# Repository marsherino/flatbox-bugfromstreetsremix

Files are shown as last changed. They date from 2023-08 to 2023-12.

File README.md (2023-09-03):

# Flatbox, Bug from Streets™ Remix: a low profile, low cost leverless arcade controller with right thumb action button and simplified fourth column.

This repository contains 3D-printable models and the PCB design files needed to make an arcade controller that looks like this:

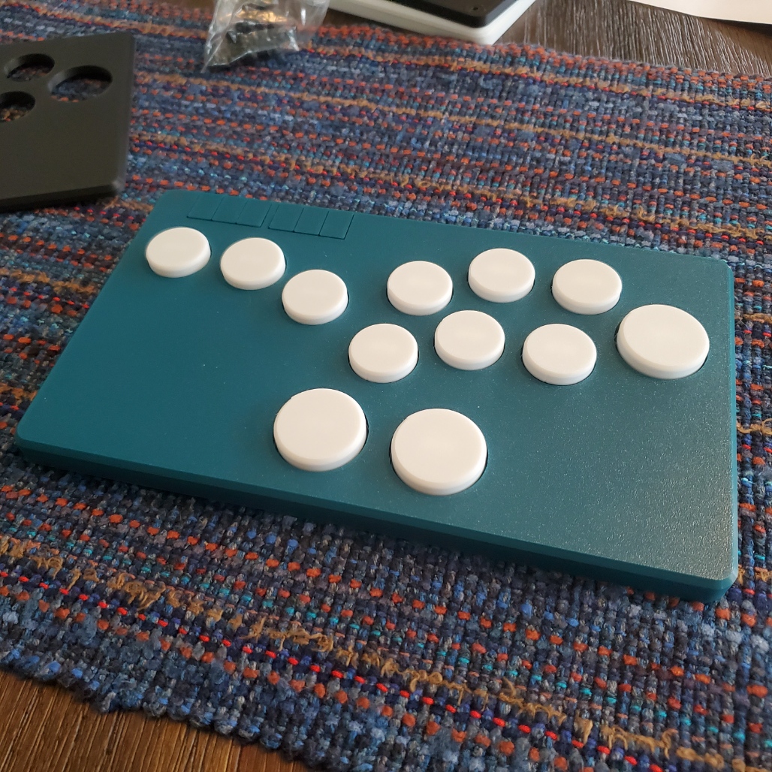
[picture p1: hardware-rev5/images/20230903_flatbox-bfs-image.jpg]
Flatbox BFS Remix


There are two versions of this controller on this Flatbox fork: one based on the architecture of the Flatbox rev4 (embedded RP2040 chip), and the other based on the Flatbox rev5 (Waveshare RP2040-Zero), both originally by jfedor2. The rev5 version of this remix is complete and available; the rev4 version is still in development.

Please see the READMEs for each version for instructions on component purchasing and assembly.

Both controllers run on [GP2040-CE firmware](https://gp2040-ce.info/) developed by the Open Stick Community and use Kailh low profile Choc v1 keyboard switches for both movement and action buttons.

Both controllers have five input modes: XInput, Nintendo Switch, PS3, PS4, and keyboard.

The table below lists each version's specifications.

version | [rev4] | [rev5]
------- | --------------------- | ---------------------
case dimensions | 218x130x10mm | 218x126x10mm
chipset | embedded RP2040 | [RP2040-Zero](https://www.waveshare.com/rp2040-zero.htm)
port | USB-C | USB-C
SMT assembly required | yes | no

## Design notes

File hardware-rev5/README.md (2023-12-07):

# Flatbox rev5

This is rev5 of the Flatbox. In this version an [RP2040-Zero](https://www.waveshare.com/rp2040-zero.htm) board is soldered onto the main PCB. This eliminates the need for SMT / SMD Assembly, which reduces the per-board cost from your PCB supplier (I use JLCPCB) in exchange for requiring slightly more soldering work from you. This makes it ideal for hobbyists and small board runs in general.

To make one unit you will need:

* [3D printed case parts](3d-printed-case), a top and a bottom;
* [The Flatbox PCB](pcb), ordered per the instructions below;
* [A RP2040-Zero](https://www.waveshare.com/rp2040-zero.htm), making sure you get the option **without header**;
* Twelve (12) [Kailh Choc v1 Low Profile switches](https://chosfox.com/collections/kailh-low-profile-switch-pg1350/products/kailh-low-profile-choc-switches) of your choice;
* Twelve (12) [Kailh Choc PG1350 hotswap sockets](https://chosfox.com/products/kailh-choc-switch-1350-hot-swap-sockets?_pos=1&_sid=1d99bca9e&_ss=r), optional but highly recommended;
* A set of [3D printed buttoncaps](../3d-printed-buttoncaps), nine (9) at 24mm size and three (3) at 30mm size;
* Six (6) [6x6x5mm tact switches](https://www.amazon.com/dp/B07VSNN9S2), noting that you'll need tact switches with longer stems if you use another case design that uses either the plain stems or stem caps instead of integrated button tabs;
* Seven (7) [M3x6mm flat head screws](https://www.amazon.com/dp/B01E5EOIWW);
* Some kind of rubber feet (6mm / 0.25 in preferred) or non-slip padding for the bottom;
* A strong adhesive to attach the feet (I use epoxy);
* Non-marking tape, like blue painter's tape; and
* Soldering equipment.

## Ordering the Boards

I order my boards from [JLCPCB](https://jlcpcb.com/).

1. Make an account and sign in.

2. Click "order now" at the top right of the screen.

3. You will see the following page:

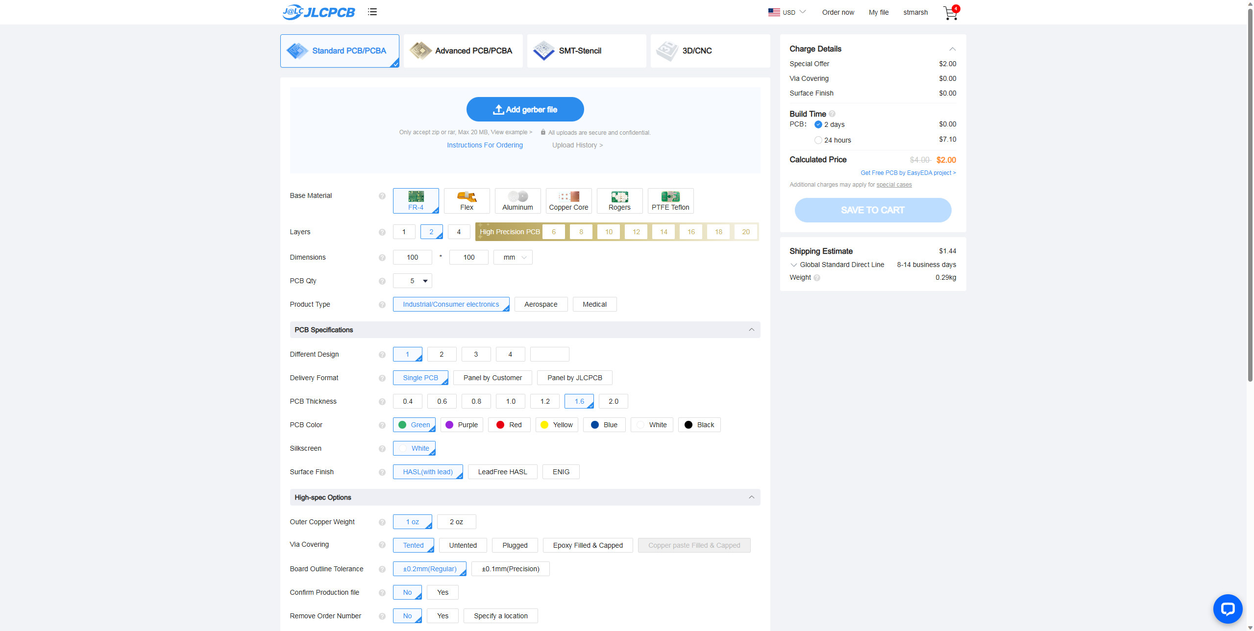
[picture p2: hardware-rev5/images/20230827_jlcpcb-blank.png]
JLCPCB blank page


Download the Gerber files included in this repository, click the blue button that reads "Add Gerber file," and upload the Gerber file. It will need to be a .zip or .rar file for JLC to accept it.

4. You will then see the following page:

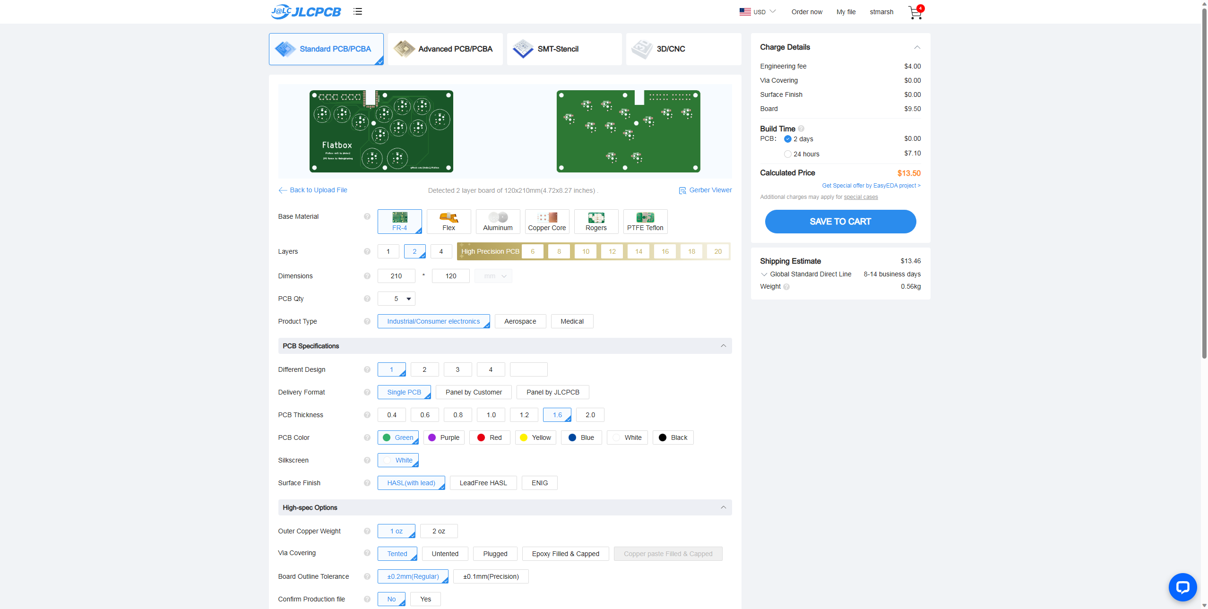
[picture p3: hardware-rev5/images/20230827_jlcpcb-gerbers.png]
JLCPCB with Gerbers added


You can leave most of these settings at default, but for the sake of completeness, here are the settings I use:

* **Base Material**: FR-4 (default)  
* **Layers**: 2  
* **Dimensions**: auto-populated, do not adjust  
* **PCB Quantity**: As many as you want, minimum of 5. Avoid ordering more than 50 boards in one order, because if you order more than 50, you won't be able to use Single PCB delivery format, which will require extra processing from you.  
* **Product Type**: Industrial / Consumer Electronics  
* **Different Design**: 1  
* **Delivery Format**: Single PCB  
* **PCB Thickness**: 1.6  
* **PCB Color**: Up to you. Green boards will generally ship a day or two faster than other colors.  
* **Silkscreen**: This will auto-populate depending on your color choice. Every color except for White will have a white silkscreen; the White color will have a black silkscreen.  
* **Surface Finish**: HASL (with lead) or LeadFree HASL  
* **Outer Copper Weight**: 1 oz  
* **Via Covering**: Tented  
* **Board Outline Tolerance**: ±0.2mm (regular)  
* **Confirm Production File**: Up to you. I recommend Yes here, because it will allow you to double-check the board to make sure everything's right before JLCPCB makes it for a minimal cost.  
* **Remove Order Number**: Up to you; this is a cosmetic choice. JLCPCB will print the order number on your boards somewhere if you pick No. If you pick Yes, they won't, but the order will be slightly more expensive. I usually pick Yes.  
* **Flying Probe Test**: Fully test  
* **Gold Fingers**: No  
* **Castellated Holes**: No  
* **PCB Assembly**: No  
* **Stencil**: No  

For reference, as of this writing (August 2023), 5 boards with the above settings costs about $16 USD before shipping. 50 boards will cost about $70 USD before shipping.

5. Click "Save to Cart," check out, and complete your order.

## Assembling the PCB

1. Once you've received all your parts, set out your soldering workspace:

Soldering layout

When soldering, make sure your workspace is clean and that you have adequate ventilation - this can be as simple as opening a window and running a fan away from your workspace. For this project, it's easy to do all of the work on a flat surface, so I just use non-marking, low-adhesion tape like blue painter's tape to hold down the PCB while I'm working on it. When working with solder, **make absolutely sure** that you wash your hands before and after soldering; do not eat or place your hands near your eyes or mouth while working; and make sure you ground yourself (either by using an anti-static wristband or by touching a grounded metal object, like the screw in a lightswitch plate) before you handle electronics.

2. Tape down your board and preheat your soldering iron per the standards for your solder. For standard leaded, rosin-core solder (what I use and recommend), I tend to work at 350 to 360°C, but you can go higher depending on your preferences.

Taped board

3. Align the RP2040-Zero. You want to make sure that all of the castellated pins on the board (the silver areas with the small holes) align with the pads on the PCB.

aligned board

4. Tape down the RP2040-Zero. You only need to leave a couple of pins at the bottom exposed for now - once those are soldered, the board will hold in place and you can remove the tape.

taped rp2040

If you prefer, it's also possible to apply some solder to the pad in the top-left and in the bottom right, place the board, and heat up the solder to set the board. I prefer the tape to minimize the number of times I have to pass over the same pad.

5. Solder the bottom pins. To solder these, hold your preheated iron to the pin for a few (2-3) seconds, and then introduce the solder wire. 

soldering iron process

You don't need to use a lot of solder; your goal is just to make sure that there is solder touching both the pad on the PCB and the side of the pin on the board, without any solder crossing over to any other pin or pad to the left or right. Using rosin flux makes this process *significantly* easier. You can either buy rosin on its own or buy solder wire with a rosin core. I prefer the latter. You can use the tip of your iron to "paint" the solder so that it's contacting both the pin and the pad.

When you're done with the bottom pins, it should look something like this:

bottom pins

6. Remove the tape and solder the rest of the pins:

fully soldered rp2040

Note that not all of the pins on the RP2040 are used in the layout of the Flatbox rev5, but I solder all of them for the sake of completeness and to better secure the board.

7. Prepare to place the tact switches. The housing for the switch will have a longer side and a shorter side with a foot in each of the four corners. Line up the switches so that the long side is parallel to the left or right side of the PCB. This will be obvious when you do it; there's only one way they fit into the through-holes.

tact switch placement

8. Push the legs of all six tact switches through the holes. Make sure that you push the legs *all* the way through the holes, or the tact switches won't sit right, and probably won't fit in the case. Make sure the housing is flat against the PCB, and on the bottom of the PCB, you can see the legs sticking through the holes:

tact switch legs

9. Flip to the back of the board and solder in the tact switches. You will probably have to move the tape around your board a bit to be able to access all of the through-holes, depending on where you put it. Your goal is to get a tiny cone of solder around each of the four legs on all six switches. To do that, like before, hold your iron next to the leg for two or three seconds to heat it, and then melt a small amount of solder wire onto the leg. It doesn't have to be very pretty. As long as there's solder around the leg, you're in good shape. It should look something like this:

soldered tact switches

10. Place your hotswap sockets as pictured, aligning them within the footprints at the top of each switch location. **Be careful! Hotswap sockets are very light and easy to lose.** You will probably have to leave a couple off the board for the time being depending on the placement of your tape.

hotswap placement

*Note: If you're soldering your switches directly to the PCB, you'll use the other two holes on the switch footprint, which are through-holes and identifiable because there is metal around the circumference of the hole.*

11. Solder on one of the two pins of the hotswap socket. Because the sockets are light, you want to make sure that as you solder on the first pad, the socket stays in its holes and flat against the PCB. 

There are two ways to do this. The first is to repeat the standard process of holding your iron against the pin for two to three seconds to heat it up and then melting solder to connect the pin to the pad. The second is to melt solder onto the pad, place the hotswap socket, and *then* reintroduce your iron to liquefy the solder and bind the pin to the pad, like so:

solder on hotswap pad

I'm agnostic between these two methods. I tend to do the first (just heating the pin), but find that I sometimes do need to apply the soldering pen to the area again because the socket fell out of position. Again, this doesn't need to be very pretty, nor do you need to use much solder. You just have to make sure there's solder on *both* the socket's pin and the PCB's pad. It'll look something like this:

hotswap one pad complete

12. Solder the other pin of the socket onto the corresponding pad.

13. Repeat steps 11 and 12 until all twelve of the sockets are soldered:

soldered sockets

14. Congratulations! Your board is soldered.

soldered board

15. Wash your hands and collect your board and your Kailh Choc switches.

board with switches

16. Begin to place your switches. Make sure the metal pins on your switches are straight. Place your switch in the footprint, lining up the metal pins with the hotswap socket:

switch placement

17. Push the switch into the socket. If you find that your socket comes loose from the board when you do so, go back to your soldering station and reattach the socket, making sure that you have solder on *both* the pin and the pad. When a socket gets dislodged for me, it's usually because the solder didn't make contact with the pad.

switch in socket

18. Repeat steps 16 and 17 until all of your switches are inserted. Congrats! At this point, your Flatbox PCB is assembled.

## Flashing the firmware

At this point, even if you don't have a case, your Flatbox is capable of working once the firmware is installed. This version of the Flatbox is designed for GP2040-CE, an open-source game controller firmware available for free online.

1. Plug a USB-C cable into your PCB, but do not plug it into a computer yet.

plugged-in PCB

2. Press and hold the BOOT button on the RP2040-Zero and, while holding the button, plug the other end of your cable into a computer. If you did it right, your computer should notify you that a drive called "RPI-RP2" has been connected. This is your PCB's memory.

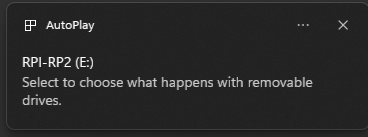
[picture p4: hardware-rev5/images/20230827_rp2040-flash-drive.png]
rp2040 drive


3. Go to the [GP2040-CE download page](https://gp2040-ce.info/#/download) and download the firmware for the Flatbox rev 5:

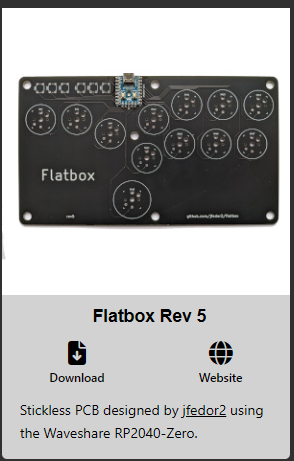
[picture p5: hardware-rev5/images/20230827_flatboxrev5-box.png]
flatbox rev5 box


4. Find the .uf2 file you just downloaded. It should have a file name that looks something like this:

uf2 file

5. Drag and drop this .uf2 file onto the RPI-RP2 drive:

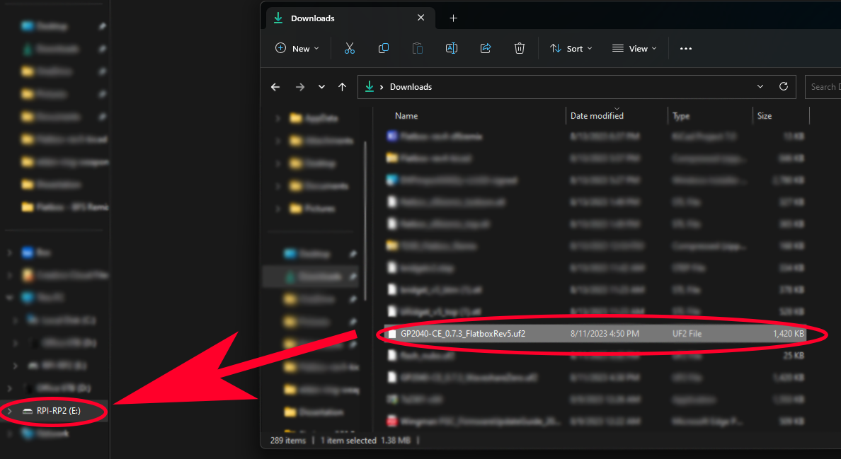
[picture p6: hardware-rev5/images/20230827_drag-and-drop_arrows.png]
drag and drop


6. Wait for about 15 seconds. On my computer, a progress chart will pop up while the file is copying, and when it's done, it closes this window and ejects the drive.

7. While your board is still plugged in, test it to make sure everything works as expected. You can do this with a gamepad tester, like [GamepadTester.net](https://gamepadtester.net/), or you can open a game and test it in training mode. I tend to do both: check the inputs on the tester first, and then open Street Fighter 6 and test it there. In the SF6 control settings, Classic Inputs Custom 1 will set the 30mm right thumb button to Parry (MP+MK)  and the fourth column 30mm button to Drive Impact (HP+HK).

8. If everything works, your board is ready to play! If you have any trouble with the firmware, one troubleshooting step is to download the [Flash Nuke .uf2 file](https://raw.githubusercontent.com/OpenStickCommunity/GP2040-CE/main/docs/downloads/flash_nuke.uf2) from the GP2040-CE site, drag and drop it onto your PCB's memory drive (which will erase any firmware), and then re-drag and drop the Flatbox Rev5 firmware onto the drive.

## 3D Printing the case and buttons

As everyone's 3D printers are different, this section will provide some general guidelines for printing the case and button caps. I print my cases on a Bambu Labs X1C through BambuSlicer, so my pictures will refer to that unit and that software. Feel free to adjust how you follow the following directions based on your own printer. If you don't have a 3D printer, look below for advice on how to obtain these parts.

### Materials

The Flatbox case and buttons can be safely printed in PLA. Note that cases printed in basic PLA have a tendency to warp; you can mitigate the risk of this somewhat by being careful with your settings. Printing the case with a brim, printing more slowly, and ensuring adequate airflow to your print bed can help. You can also print the case in different materials: Bambu's PLA-Tough and PLA-CF both work well, as do many forms of PLA+ filament, all of which can help reduce warping. PETG also works very well.

### Printing orientation

Both the case and buttons should be printed face-down, so the inside portions are the top layer:

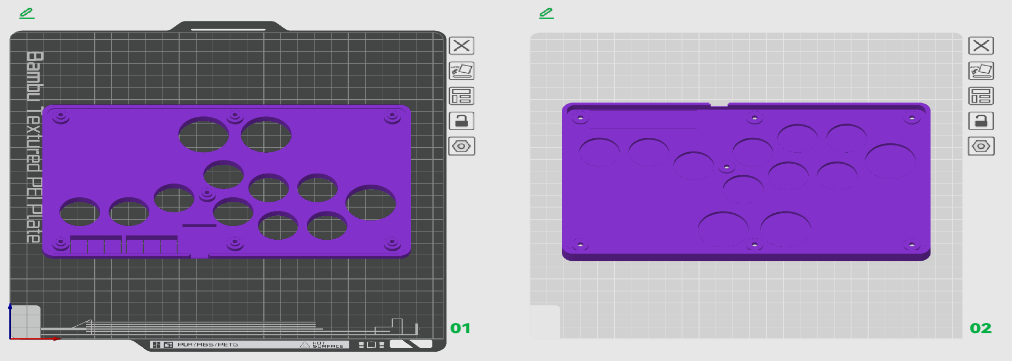
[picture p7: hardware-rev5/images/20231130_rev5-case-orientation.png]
case orientation


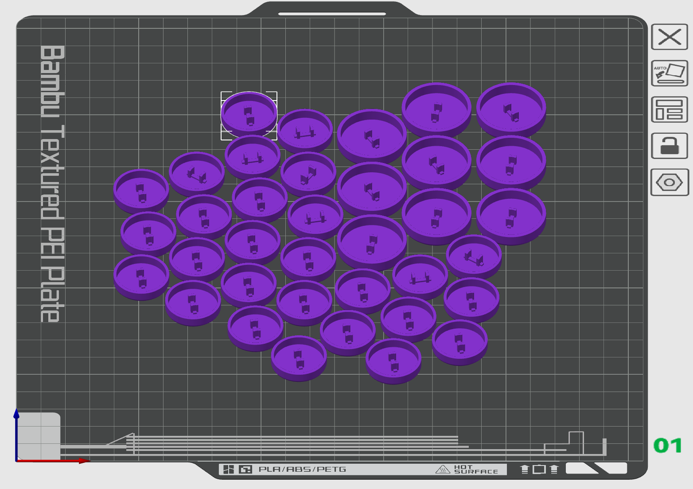
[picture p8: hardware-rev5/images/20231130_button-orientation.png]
button orientation


Printing this way accomplishes two things:

1. You won't need supports, because any overhang is isolated to the top layers, and

2. The face of your case and buttons will pick up any texture from your build plate.

### The build plate

I strongly recommend using a textured PEI build plate (rather than a smooth plate, like the Bambu Cool Plate) for printing these materials. Because the Flatbox case has a large contact area with your plate _and_ that surface is visible on the finished product, using a smooth plate significantly magnifies the risk of your print picking up surface imperfections from the plate itself, like glue stick markings, oil from your fingers, residue from previous prints, and the like. You can use a smooth plate if you're extremely thorough about cleaning your plate between every single print you do, ideally with a good dish soap and water. Moreover, smooth-printed buttons don't have a very pleasant feel. (I recommend a smooth plate only if you're printing with a transparent filament, or are very invested in the smooth finish / the visibility of your layer pattern.)

Conversely, the textured plate offers a handful of advantages. Though you'll still want to be fairly careful with your plate--avoid touching the print surface with your fingers--the textured plate is much better at hiding residue from previous prints, and you generally won't need glue to help with bed adhesion, which removes one other source of surface imperfections. The textured plate also produces an aesthetically pleasing finish on the case and better feel on the buttons.

### Print settings

Because the Flatbox case is a wide and relatively stout print, anything you can do to strengthen the print will help produce a better finished product. I find that I get good prints with a **0.16mm layer height (though 0.2mm will also work)**. Printing with **3 or 4 walls**, approximately **4 each of top and bottom layers** and a **20% infill** helps give the case rigidity. 

If you're printing with a transparent filament, you can adjust these values to something like **6 walls** and **5 each of top and bottom layers** and consequently drop the infill to **5 or 10%**, which will let you take advantage of the transparency more. You will still need some infill, or the parts of the case far from the walls (the open areas in the bottom left and right of the case) will cave in.

### Calibrating the button stems

Moreso than the case, printing the button caps can be a little fiddly because the stems have to be able to fit well into the openings on your Choc v1 switches. One way to deal with this is to make adjustments to your X-Y contour compensation (on BambuSlicer) or equivalent on your slicing software:

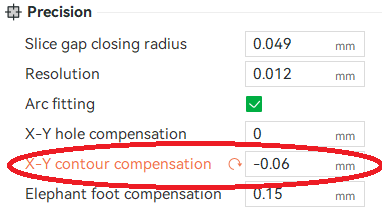
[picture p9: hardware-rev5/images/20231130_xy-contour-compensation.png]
slicer software xy-compensation


One tactic I learned from Matt at [SGF Devices](https://sgfdevices.com/) for figuring out what compensation you need is to print a "calibration sheet" of four button caps, each object having -0.03 more X-Y contour compensation than previous, and test them in a switch every time you load a new filament:

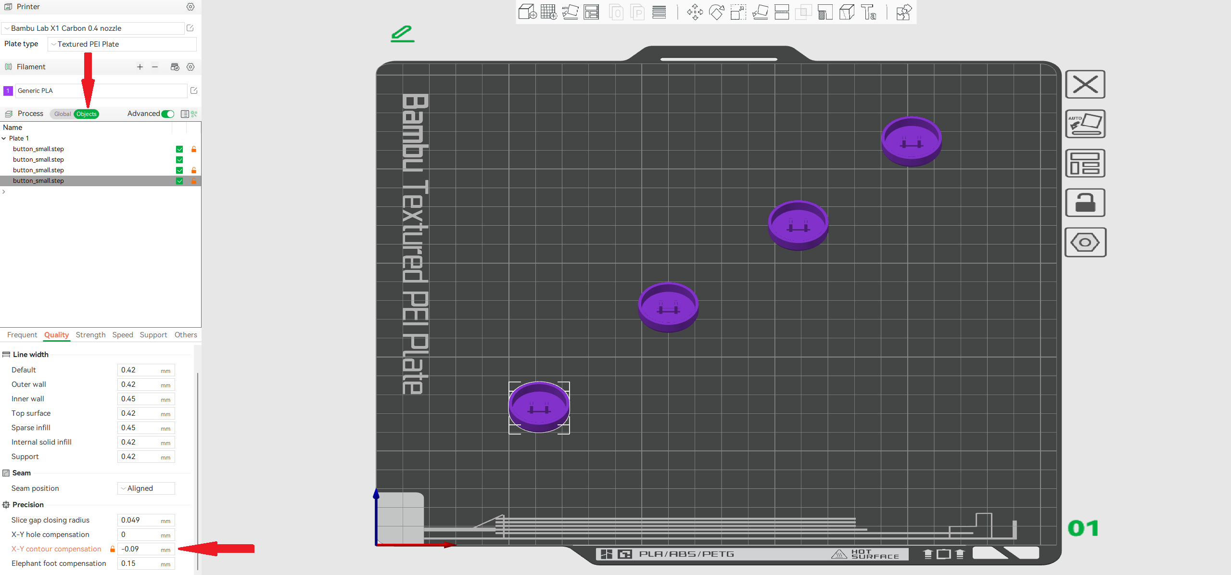
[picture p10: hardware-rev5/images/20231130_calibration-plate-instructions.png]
dealing with the calibration sheet


You're looking for the cap to fit snugly, but not too tightly, into your switch. If they're too big, they either won't fit into your switch, or if they do, they may become impossible to remove without breaking the cap. If they're too small they'll fall out of the switch. You want the switch to be able to hold the cap stem firmly, but you also want to be able to remove the cap if necessary. When you find your X-Y contour compensation value, write it on a piece of painter's tape and attach it to the side of your filament spool so you can remember for the future.

That said, even taking every possible precaution, these button caps are inherently fragile and some will break if you try to remove them. Always remember to print out extra button caps of both sizes to have handy for when this happens. Alternately, you can follow the instructions below to obtain some nylon printed button caps from JLCPCB, which are exponentially sturdier than home-printed buttons.

### Print timing

On my printer with the above settings, I can print a sheet of three sets of buttons in about 1 hour and 45 minutes, and each half of the case in about two hours, for a total of **four hours** for the case and a little under **six hours** for all parts, not counting time spent removing objects and maintaining your build plate.

## How to get a case if you don't have a 3D printer

If you don't have your own 3D printer, you'll have to obtain a case and button caps some other way. By far the easiest way to do this is to buy your parts from someone who has a 3D printer. On the Open Stick Community discord, there are many creators who would be willing to sell you a high quality case and button caps for a reasonable price; you can also find makers on Etsy who will do the same (though it might be slightly more expensive after Etsy's fees.) I've found that the cost for printing these materials on ship-and-print commercial 3D printing services is far higher than you would spend with either of these other two options.

### A note on public printers (libraries and makerspaces)

Many people have successfully printed Flatbox parts on shared and publicly-accessible 3D printers, of the sort you'd find in a public library or in a local makerspace. If you're considering going this route, keep the following things in mind:

1. Many public printers can be quite slow. The above printing times are those of a fast home printer, and it wouldn't be out of the ordinary for a different printer to take twice as long or longer to print the same parts.

2. Likewise, public printers can print in wildly different qualities depending on how well they've been maintained. Many public printers have not been well maintained, and will print your parts badly. The Flatbox case is a demanding print with a large, flat surface area in a visible location that, ideally, needs to look good. It is not a functional print whose finish quality does not matter. Check with your source to make sure the printer has been well maintained, and if in doubt, see if you can do a quick test print to assess the quality of the bottom layer in particular. Be aware in any case that a print on a public or shared printer might not come out at the quality you expect.

3. Finally, even if you find a well-maintained printer, be mindful of others. Because the print can take a long time, make sure you communicate the print length up-front to whomever is managing the printer and make sure it's OK to take up the printer for that period of time. If you're required to stay with the printer while it's printing, bring something to occupy yourself, and consider doing the three prints at different times to break up how long you're using the printer at once.

### An alternate option for button caps (Nylon)

One alternate option for getting a set of button caps is to have JLCPCB print you a set of caps in MJF Nylon. Even if you have a 3D printer, you might want to consider getting your button caps this way: these caps have great surface feel and, crucially, are *significantly* sturdier than home-printed button caps, being very unlikely to break. Note that, barring you spending a truly incredible amount of money, these only come in black. Here's how you can order some:

1. Download the two .stls in the [MJF (Nylon) Button Sprues](3d-printed-case/buttons/MJF%20(Nylon)%20Button%20Sprues/) subfolder on this repo. Each of these is a "sprue," a connected set of eight button caps. **You'll need to get at least one of each sprue to have enough button caps to fill your device.**

2. Log into JLCPCB, click "order now," and navigate to the "3D / CNC" option near the top.

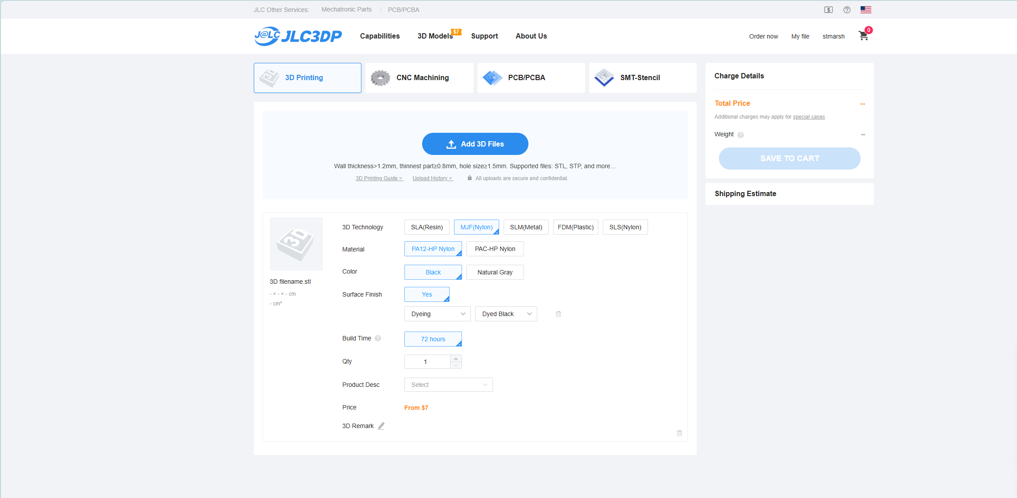
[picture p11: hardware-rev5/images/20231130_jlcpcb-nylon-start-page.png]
JLCPCB 3D order page


3. Upload one of the two .stl files to start by clicking on the blue "Add 3D Files" button.

4. Select the following settings:

* **3D Technology**: MJF (Nylon)
* **Material**: PA12-HP Nylon. You _could_ select PAC-HP Nylon to get your buttons in a color other than black, but it'll cost an order of magnitude more than just choosing PA12-HP Nylon.
* **Color**: Black. The "Natural Gray" color option doesn't look good, and assumes that you'll find some way to color them on your own.
* **Surface Finish**: These will be filled by default with "Yes," "Dyeing," and "Dyed Black" and cannot be changed, assuming you've picked the above options.
* **Build Time**: 72 hours (cannot be changed), assuming you've picked the above options.
* **Quantity**: Up to you. You only need one of each sprue to have enough caps for one Flatbox plus several extras. If you print three of each sprue, you'll have enough caps for four Flatboxes exactly.
* **Product Desc**: I usually pick "DIYEntertainment" > "Game Controller Enclosure -HS Code 950450."
* **3D Remark**: Not necessary.

5. Click "Save to Cart."

6. Repeat the above steps for the other sprue.

7. Click your cart, check out, and complete your order. For reference, as of this writing (November 2023), three sets of both sprues (total of six objects) cost me just under $30 USD shipped.

8. Note that once you've sent in your order, it is very likely that JLCPCB will get in touch with you to tell you that the wall thickness of the sprue piece itself is below their 1.5mm minimum thickness, and ask if you'd like to proceed with the print anyway:

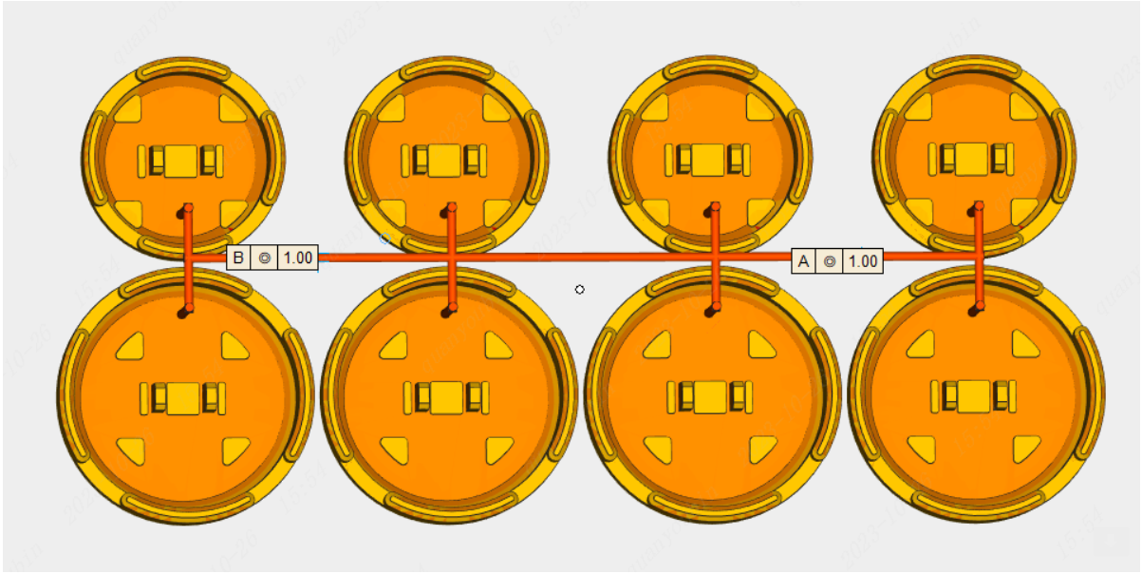
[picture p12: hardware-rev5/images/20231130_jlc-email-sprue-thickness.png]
sprue thickness issue diagram

 
 You can safely tell them to proceed with the print as-is.

Once you've gotten your case and button caps, you can proceed to installing your case.

## Installing the case

You will need to get a [3D printed case](3d-printed-case) and a set of [button caps](3d-printed-case/buttons) to proceed through this section. The files for the case and buttons are available on this repo, though Flatbox button caps designed for Choc v1 switches obtained elsewhere should also work.

1. Get the bottom portion of your case, your rubber feet (if using), and your adhesive.

foot attachment prep

2. Dispense your adhesive and, if necessary, mix it. 

ejecting epoxy

Epoxy ususally comes in two portions that need to be mixed together for the substance to set, for example. Follow the directions for your adhesive.

mixing epoxy

3. Apply your adhesive to where you want your feet to go. I tend to place mine in the corners. Use a small, fine implement - I use a toothpick - to "paint" in the adhesive, ensuring you don't use too much or it'll leak onto other parts of the case.

applying epoxy

4. Attach your feet, being careful to avoid adhesive leakage if possible and to clean any leaks promptly.

5. If necessary, allow your adhesive to cure fully before proceeding. The epoxy I use takes about an hour to cure.

feet attached

6. Gather your completed PCB, your case, your button caps, your M3x6mm screws, and a compatible screwdriver.

pcb with case prep

7. One by one, align your button caps with the openings of your switches. 

setting the button cap

Note that the 3D printed button caps used for this step (available on this repo) are *extremely* fragile and have a tendency to break at the stem. Be very careful pushing in the caps; use a light touch and make sure you have extras. 

stem detail

Push in the cap.

button inserted

If a stem breaks inside of your switch, you can carefully remove by heating up a thin needle or thumbtack, pressing it into the broken stem, and pulling the stem out when your tool cools. 

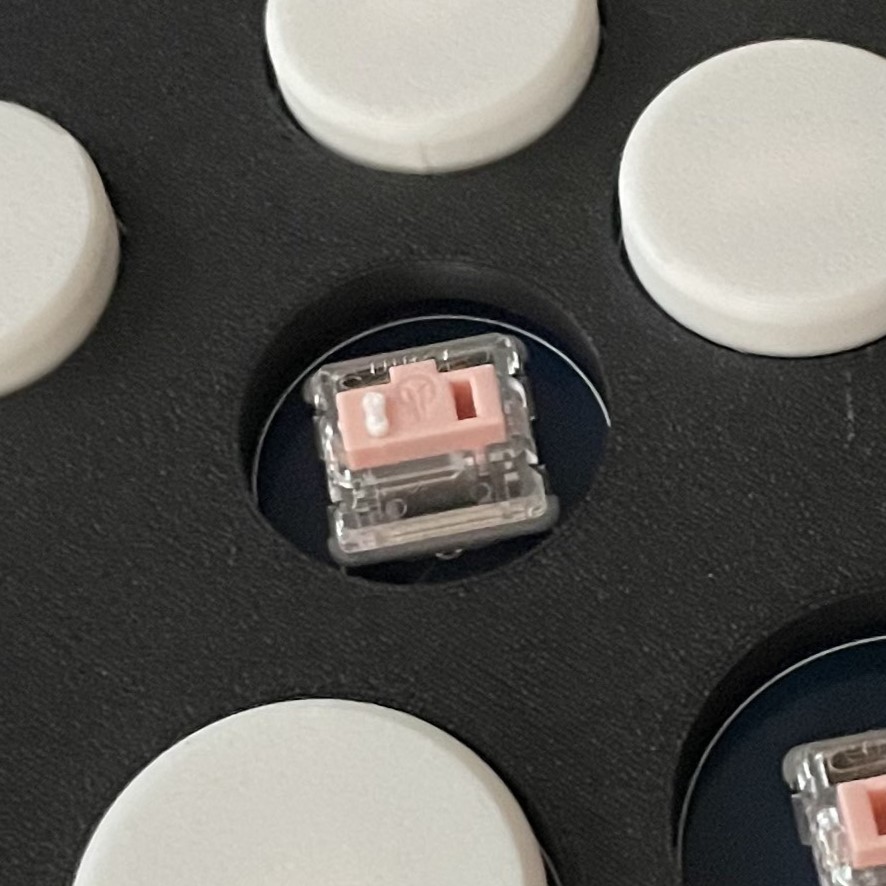
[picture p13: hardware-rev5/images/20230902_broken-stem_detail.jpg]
stem broken in switch


Remember to only remove the caps with the board outside of the case, and to grab the rim and pull straight up. Attempting to wiggle the button cap out of the switch will cause it to break.

Continue until all of your button caps are placed.

all caps placed

8. Place the top of your case over the top of your board, lining up the mounting posts in the case with the mounting holes in the PCB.

aligning the front case

9. Place the bottom of your case so that the screw holes on the bottom line up with the mounting holes on the top. They should roughly click together, but will not snap together decisively.

beginning to insert the screws

10. Begin to place your screws. Do not fully tighten them; just screw them in enough for a light hold. 

screw detail

Criss-cross your case as you place them, as if you were tightening the bolts on a car wheel. 

crisscross the screws

If you printed your case out of PLA, the machine screws recommended on this repo will be able to "bite" into the plastic on their own. Note that if you print out of a firmer material, you may need to use self-tapping screws. If you do, be careful to avoid piercing through the top of your case.

all screws inserted

11. When all of your screws are placed, begin to tighten them in. Keep a close eye on the flatness of the case as you do this. I find that if I tighten in all the screws all the way, some case flex inevitably gets introduced:

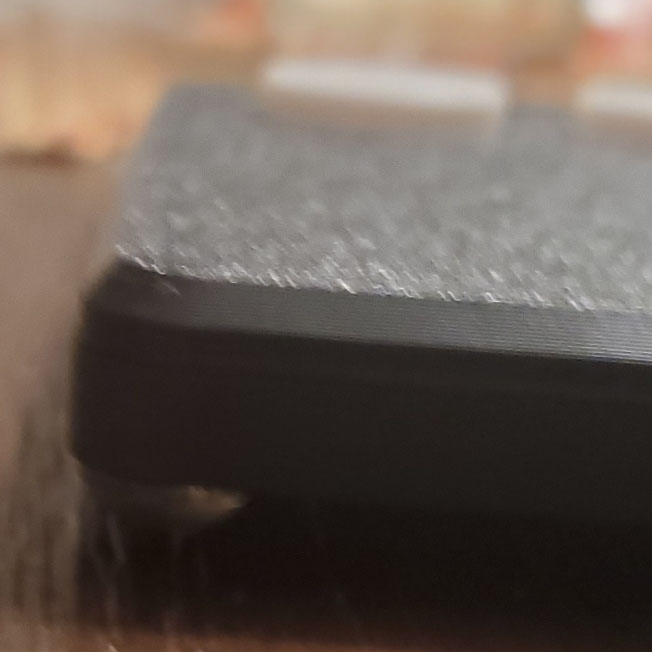
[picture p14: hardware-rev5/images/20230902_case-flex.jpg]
example case flex


Tighen them only as much as possible without introducing any flex in the case.

12. Once you've installed your case, go back to your computer or console and test it again to make sure everything still functions as expected and that you like the feel of your switches.

**Congratulations! Your Flatbox rev5 - Bug from Streets™ Remix is now complete and ready for anything.**

it is done

---

PCB design licensed under [CC BY-SA 4.0](https://creativecommons.org/licenses/by-sa/4.0/).

PCB design uses the following:

* [keyswitches.pretty](https://github.com/daprice/keyswitches.pretty) by [daprice](https://github.com/daprice) ([CC BY-SA 4.0](https://creativecommons.org/licenses/by-sa/4.0/))
* RP2040-Zero STEP file downloaded from [Waveshare wiki](https://www.waveshare.com/wiki/RP2040-Zero)

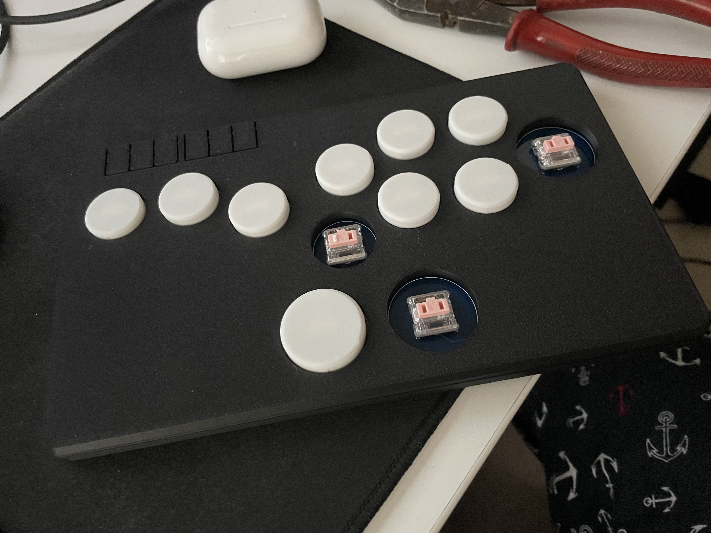
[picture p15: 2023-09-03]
hardware-rev5/images/20230902_broken-stem.jpg

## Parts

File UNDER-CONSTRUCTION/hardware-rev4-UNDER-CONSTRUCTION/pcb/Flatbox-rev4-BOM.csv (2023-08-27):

Comment | Designator | Footprint | LCSC
30p | C2,C3 | Capacitor_SMD:C_0402_1005Metric | C1570
1u | C1,C4,C8,C10 | Capacitor_SMD:C_0402_1005Metric | C52923
100n | C5,C6,C7,C9,C11,C12,C13,C14,C15,C16 | Capacitor_SMD:C_0402_1005Metric | C1525
10k | R2 | Resistor_SMD:R_0402_1005Metric | C25744
27 | R3,R4 | Resistor_SMD:R_0402_1005Metric | C138021
1k | R1,R5 | Resistor_SMD:R_0402_1005Metric | C11702
5.1k | R6,R7 | Resistor_SMD:R_0402_1005Metric | C25905
SW_Push | SW1,SW2,SW3,SW4,SW5,SW6 | Button_Switch_THT:SW_PUSH_6mm_H5mm
SW_Push | SW19,SW20 | Button_Switch_SMD:SW_SPST_Omron_B3FS-100xP | C271750
SW_Push | SW7,SW8,SW9,SW10,SW11,SW12,SW13,SW14,SW15,SW16,SW17,SW18 | Kailh:Kailh_socket_PG1350_optional
TLV73333PDBV | U1 | Package_TO_SOT_SMD:SOT-23-5 | C134139
W25Q128JVS | U2 | Package_SO:SOIC-8_5.23x5.23mm_P1.27mm | C97521
RP2040 | U3 | RP2040:RP2040-QFN-56 | C2040
HRO-TYPE-C-31-M-12 | USB1 | Type-C:HRO-TYPE-C-31-M-12-Assembly | C165948
Crystal_GND24 | Y1 | Crystal:Crystal_SMD_3225-4Pin_3.2x2.5mm | C9002

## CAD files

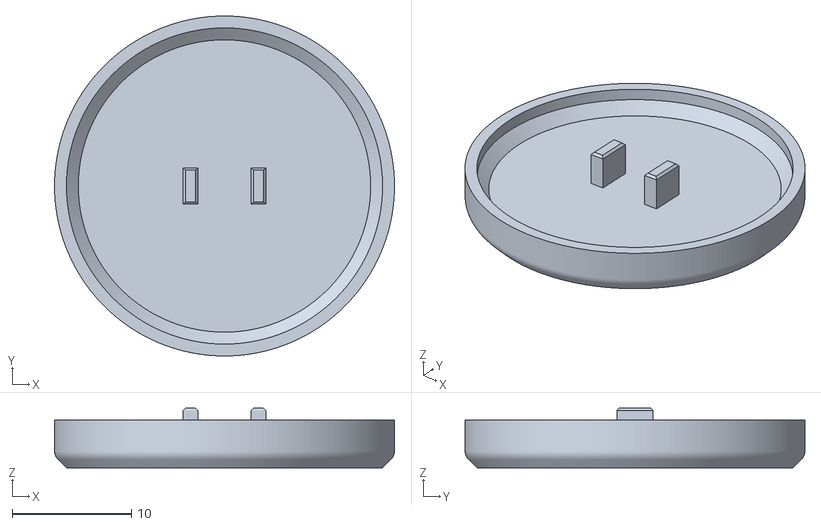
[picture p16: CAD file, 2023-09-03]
hardware-rev5/3d-printed-case/buttons/ButtoncapBig.stl
28.5 x 28.5 x 5.00

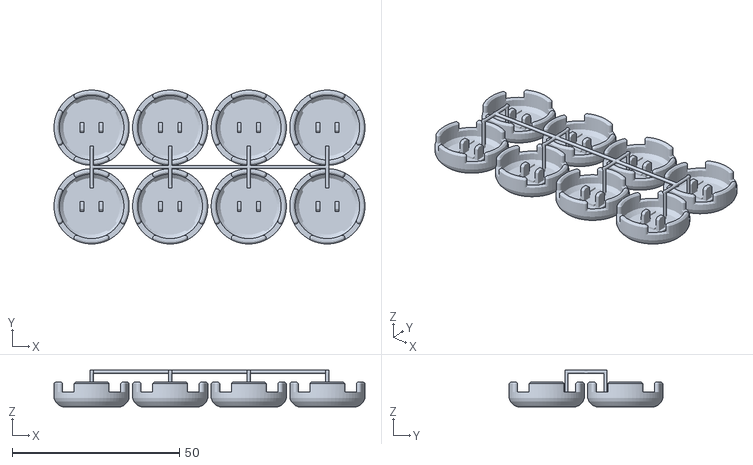
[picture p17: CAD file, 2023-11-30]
hardware-rev5/3d-printed-case/buttons/MJF (Nylon) Button Sprues/8x24mm_sprue.stl
93.0 x 46.0 x 11.0

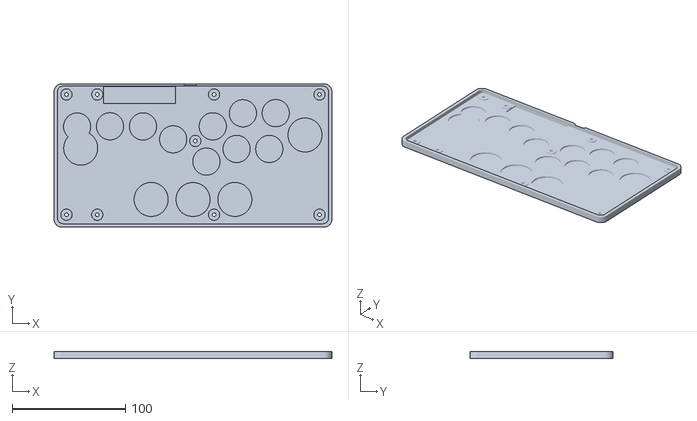
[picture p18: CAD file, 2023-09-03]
hardware-rev5/3d-printed-case/extra-wide-case/flatbox_bfsremix_bottom_wide.stl
245.2 x 126.4 x 6.20

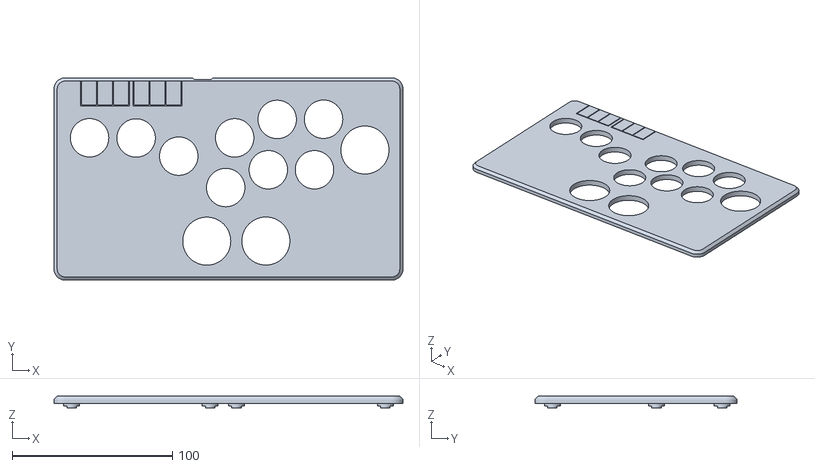
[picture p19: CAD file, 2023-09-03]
hardware-rev5/3d-printed-case/standard-case/flatbox_bfsremix_top.stl
218.0 x 126.4 x 7.20

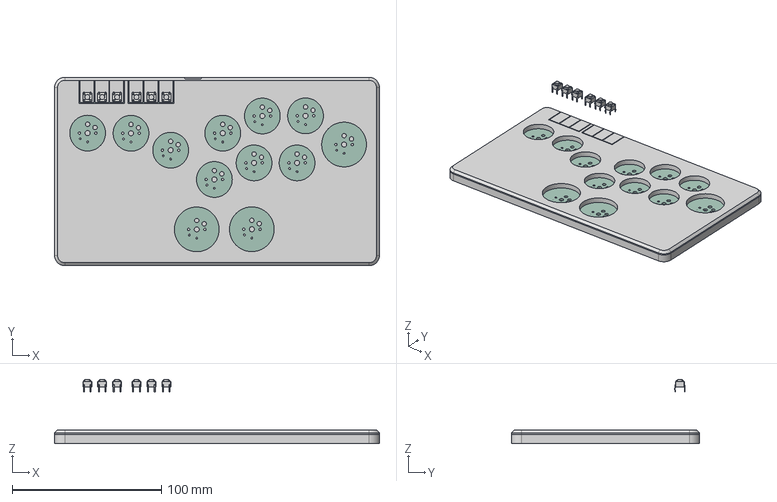
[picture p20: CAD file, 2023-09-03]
hardware-rev5/extras/case_Flatboxrev5_BFSRemix.step
218.0 x 126.4 x 43.1 mm

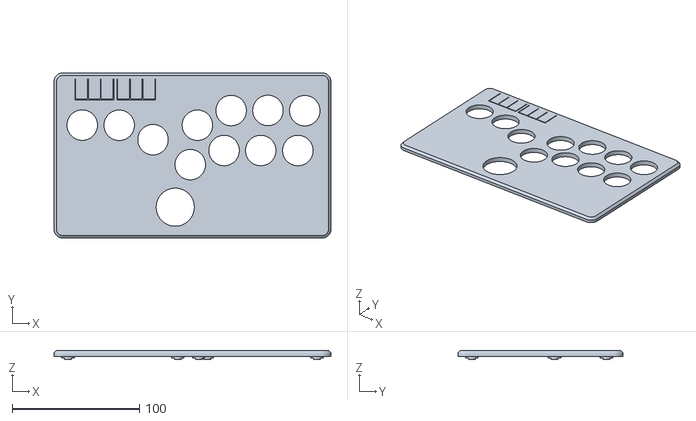
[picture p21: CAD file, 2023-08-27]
UNDER-CONSTRUCTION/hardware-rev4-UNDER-CONSTRUCTION/3d-printed-case/Flatbox-rev4-Top.stl
218.0 x 130.1 x 7.20

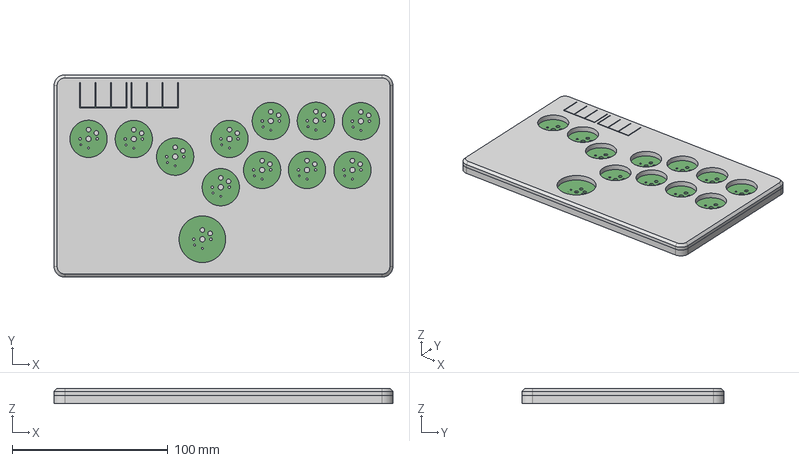
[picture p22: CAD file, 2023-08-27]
UNDER-CONSTRUCTION/hardware-rev4-UNDER-CONSTRUCTION/extras/Flatbox-rev4-case.step
218.0 x 130.1 x 9.80 mm

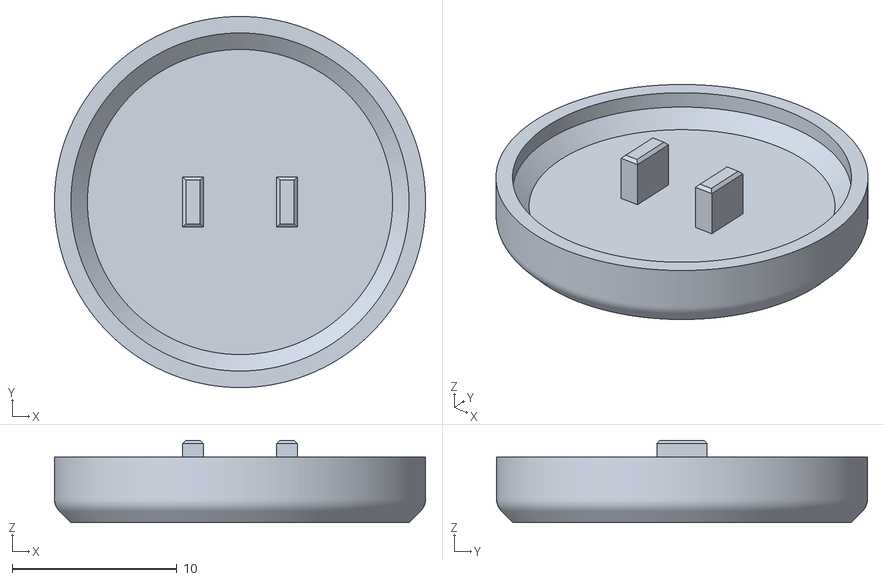
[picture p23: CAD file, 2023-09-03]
hardware-rev5/3d-printed-case/buttons/Buttoncap.stl
22.5 x 22.5 x 5.00

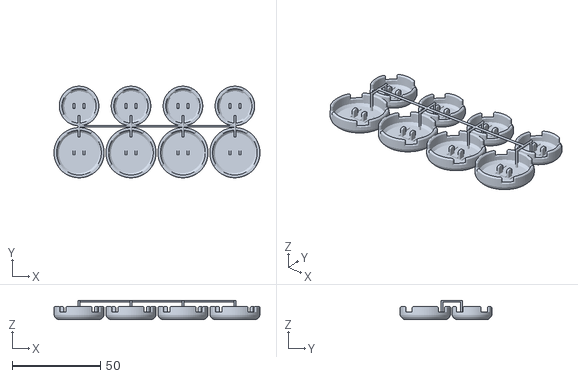
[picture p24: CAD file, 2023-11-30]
hardware-rev5/3d-printed-case/buttons/MJF (Nylon) Button Sprues/4x24mm__4x30mm_sprue.stl
116.9 x 52.0 x 11.0

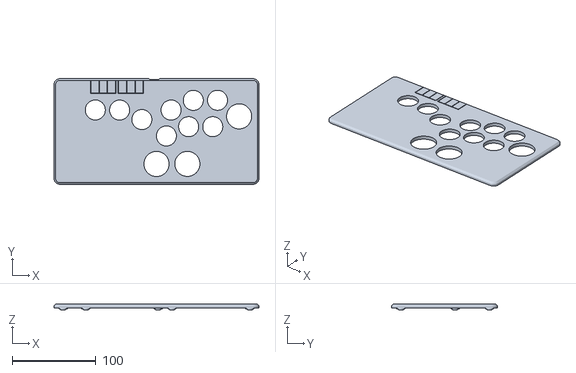
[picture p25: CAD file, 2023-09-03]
hardware-rev5/3d-printed-case/extra-wide-case/flatbox_bfsremix_top_wide.stl
245.2 x 126.4 x 7.20

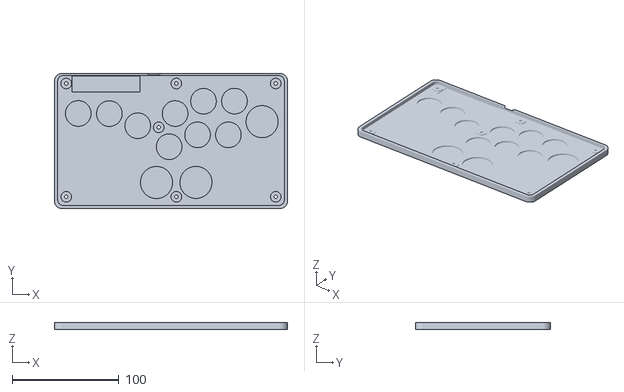
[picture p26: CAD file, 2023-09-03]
hardware-rev5/3d-printed-case/standard-case/flatbox_bfsremix_bottom.stl
218.0 x 126.4 x 6.20

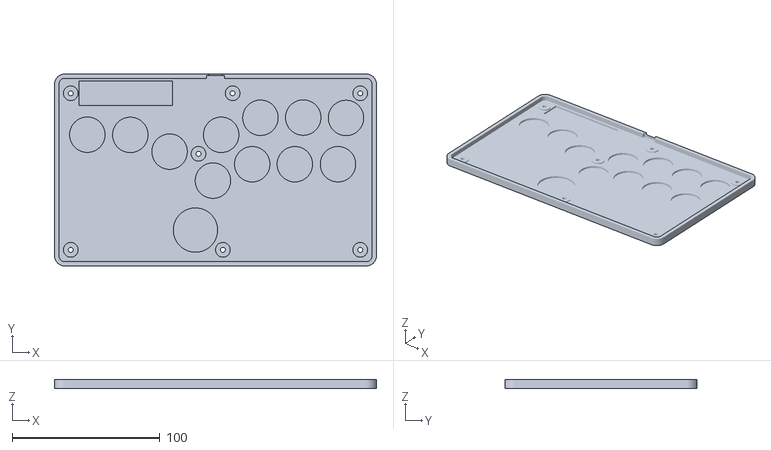
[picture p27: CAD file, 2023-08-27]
UNDER-CONSTRUCTION/hardware-rev4-UNDER-CONSTRUCTION/3d-printed-case/Flatbox-rev4-Bottom-hotswap.stl
218.0 x 130.1 x 6.20

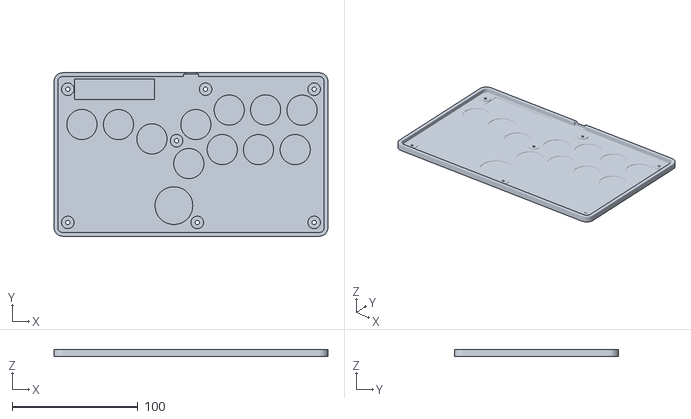
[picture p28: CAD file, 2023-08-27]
UNDER-CONSTRUCTION/hardware-rev4-UNDER-CONSTRUCTION/3d-printed-case/Flatbox-rev4-Bottom.stl
218.0 x 130.1 x 5.20

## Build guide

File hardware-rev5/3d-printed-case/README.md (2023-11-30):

This folder includes several versions of the .stl files needed to make a 3D printed case for the Flatbox rev5 - Bug from Streets™ Remix. 

The normal version replicates the dimensions of the original Flatbox case and was designed by me, based on the original file by jfedor2. 

The extra-wide version was kindly provided by lethalmonk6, and is approximately 245mm wide (with length and height remaining the same.) The extra-wide version requires 9 screws to secure the case instead of 7, though with the pcb files provided here, the leftmost two screws will not mount into the pcb. 

Whichever version of the case you print, make sure that you use the top and bottom parts of the same version. Both parts will be in the corresponding folder.

The case should be printed at a 0.20mm layer height and a 15-20% infill. The bottom part should be printed as oriented in the .stl; the top part should be printed upside-down. When printed in this orientation, you won't need supports to print any part of the case.

The button .stl files available here are jfedor's original button design. I recommend SGF Devices's revised Bridget buttons for the Choc v1, which are sturdier, and are available [here](https://github.com/sgfdevices/Bridget/tree/main/Buttons/deprecated%20versions/v1%20stems). There are a number of other alternate designs for the button caps that, for example, print the stems as separate pieces to be glued into the tops or model the housing differently; I encourage you to do your research and find a cap design that works for you. The buttons should be printed upside-down, and will not need supports.

If you do not own a 3D printer, you may find it easier to get a set of buttons printed in MJF Nylon by JLCPCB when you order your boards. The files can be found in the "MJF (Nylon) Button Sprues" subfolder in the "Buttons" folder above, and were also designed and kindly provided by lethalmonk6.

You will need 9 small buttons (24mm) and 3 large buttons (30mm) for this remix.

If you want to make your own revision of the case, the .step file is available in the "Extras" folder. You will need some form of CAD software (I use Fusion 360) to modify it. If you design a case revision that you think others might enjoy, feel free to get in touch with me and we can discuss hosting it on this repo.

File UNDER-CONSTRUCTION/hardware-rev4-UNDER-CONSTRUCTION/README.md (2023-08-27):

# Flatbox rev4

This is rev4 of the Flatbox. In this version the PCB includes a microcontroller and USB port. Everything is built in, you only have to add the switches (and flash the firmware).

To make one you will need:

* [3D printed case parts](3d-printed-case) - top and bottom
* [the PCB](pcb)
* 12x Kailh low profile (choc v1) switches of your choice
* (optionally) 12x Kailh low profile hotswap sockets
* [3D printed buttoncaps](../3d-printed-buttoncaps)
* 6x 6x6x5mm tact switches
* 7x 3x10mm wood screws
* some kind of rubber feet or non-slip padding for the bottom
* a soldering iron

I printed the case at 0.20mm layer height. The top part should be printed upside-down, the bottom part should be printed as-is. They don't require supports.

I used [JLCPCB](https://jlcpcb.com/) to make the PCB and assemble the SMD parts. The [included files](pcb) can be used with JLCPCB directly. If you want to use some other service, check the file formats that they expect. When ordering from JLCPCB, upload the Gerber zip, leave all the settings at default (you can choose the PCB color), then select "SMT Assembly" and upload the BOM and CPL files. PCB thickness should be 1.6mm.

The PCB you get from JLCPCB will look like this:

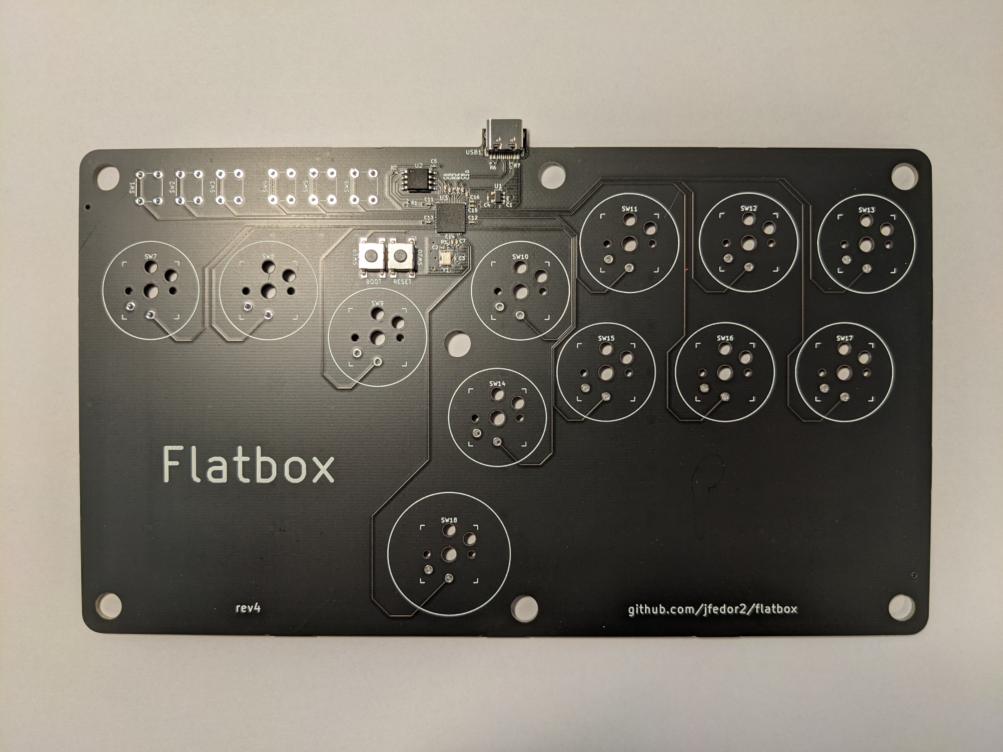
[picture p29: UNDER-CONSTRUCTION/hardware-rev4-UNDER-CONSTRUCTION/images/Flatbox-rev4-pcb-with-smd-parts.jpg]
Flatbox rev4 PCB with SMD parts assembled


The switches can be soldered in directly to the PCB or you can use hotswap sockets. If you want to use hotswap sockets, you will have to print the appropriate bottom part of the case (it's 1mm thicker).

You don't have to use the [code](../firmware-rp2040) included here, you can use any other RP2040-compatible firmware. The included firmware works with the PS3 and PC.

To flash the firmware, connect the PCB to a computer with a USB cable, then press the RESET button while holding the BOOT button on the PCB. A drive named "RPI-RP2" should appear. Copy the [flatbox-rev4.uf2](firmware/flatbox-rev4.uf2) file to that drive. That's it.

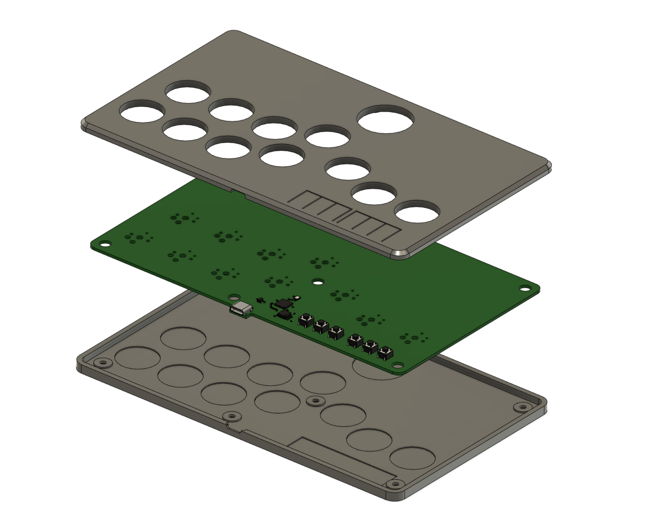
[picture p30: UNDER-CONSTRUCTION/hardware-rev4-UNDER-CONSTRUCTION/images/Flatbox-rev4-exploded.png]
Flatbox rev4 exploded view of the 3D printed case


PCB design licensed under [CC BY-SA 4.0](https://creativecommons.org/licenses/by-sa/4.0/).

PCB design uses the following libraries:

* [keyswitches.pretty](https://github.com/daprice/keyswitches.pretty) by [daprice](https://github.com/daprice) ([CC BY-SA 4.0](https://creativecommons.org/licenses/by-sa/4.0/))
* [Type-C.pretty](https://github.com/ai03-2725/Type-C.pretty) by [ai03-2725](https://github.com/ai03-2725)
* RP2040 library from the [minimal design example](https://datasheets.raspberrypi.org/rp2040/Minimal-KiCAD.zip) from the [Hardware design with RP2040](https://datasheets.raspberrypi.org/rp2040/hardware-design-with-rp2040.pdf) document

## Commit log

2023-08-27 Wrote PCB assembly walkthrough in rev5-README
    [Flatbox-rev4-BOM.csv, Flatbox-rev4-Bottom-hotswap.stl, Flatbox-rev4-Bottom.stl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]
2023-08-27 Fixed folder naming
    [Flatbox-rev4-BOM.csv, Flatbox-rev4-Bottom-hotswap.stl, Flatbox-rev4-Bottom.stl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]
2023-09-03 First full release of Flatbox rev5 BFS Remix
    [Buttoncap.stl, ButtoncapBig.stl, Flatbox-rev4-BOM.csv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]
2023-11-30 Added 3D printing documentation
    [4x24mm__4x30mm_sprue.stl, 8x24mm_sprue.stl]
